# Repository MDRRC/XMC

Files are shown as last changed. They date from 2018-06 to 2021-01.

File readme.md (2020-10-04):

# Xpressnet Manual Control

The XpressNet Manual Control (Xmc) is manual control for the [XPressnet bus](www.lenzusa.com/1newsite1/Manuals/xpressnet.pdf) based on 

 * An [Maple Mini STM32 board](https://www.leaflabs.com/maple/) variant from China with **128K flash** memory and not the 64K variant!
 * RS485 driver IC
 * AT24C256 memory IC for storage of settings and locomotive data.
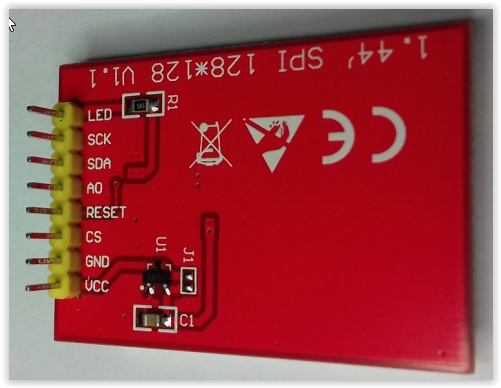
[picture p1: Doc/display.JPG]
 * 128*128 pixel ST7735 LCD. When ordering a display make sure the pinning is the same as shown in image below
 * Push buttons for controlling functions / accesory decoders / menu related actions. 
 * Pulse switch for setting speed / menu related actions.
 
The user interface is nearly the same as with the WMC application and it's tried to reuse / update library's created for WMC.

## Tested with
 * [MDRRC-II](http://members.home.nl/robert.evers/mdrrc2.htm) Response ok. 
 * [Roco MultiMaus as master](https://www.roco.cc/en/product/5215-multimaus-0-0-0-0-0-004001-0/products.html) OK for locs, turnouts not tested yet.

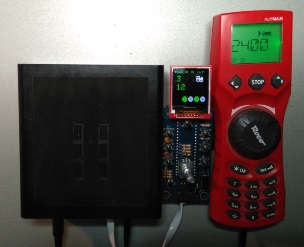
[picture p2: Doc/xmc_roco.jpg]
 
 
## Schematic
The [schematic](https://github.com/MDRRC/XMC/blob/master/Doc/xmc_schematic.pdf) of the XMC.

## PCB front and back side.
The PCB from the front and back. 
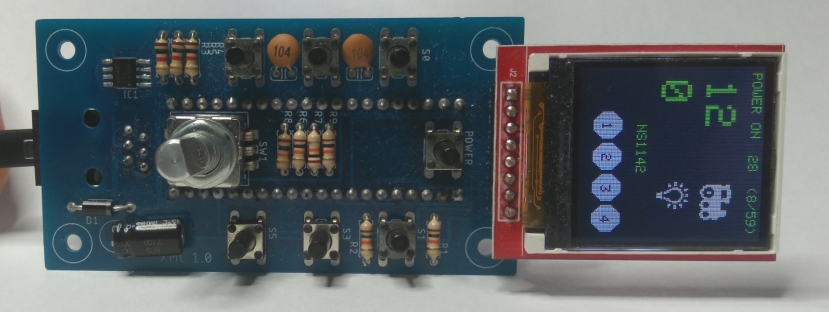
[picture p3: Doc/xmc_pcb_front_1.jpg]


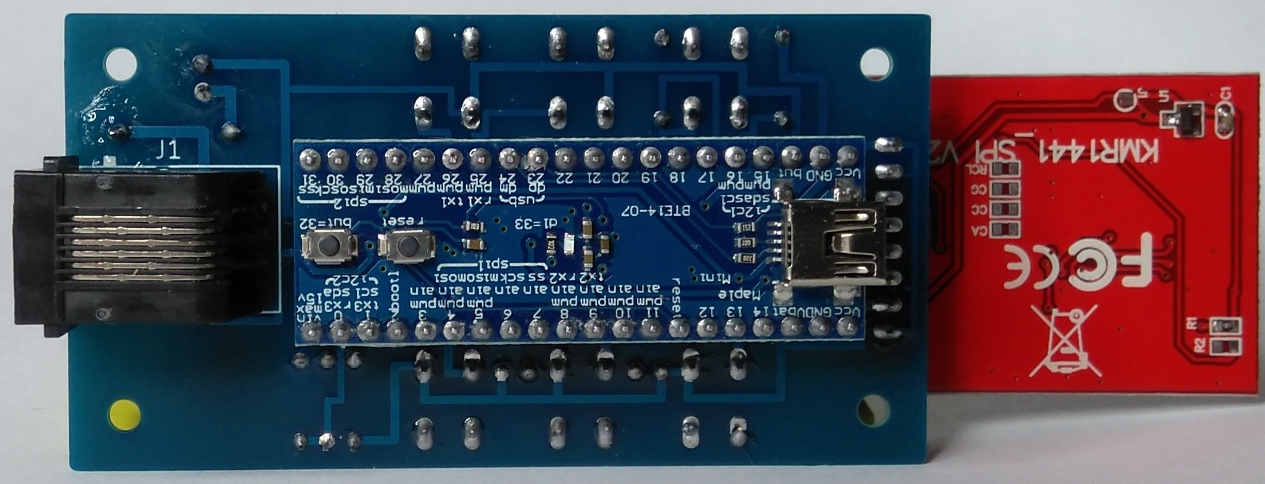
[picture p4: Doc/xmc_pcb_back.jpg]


## Programming the STM32 
The STM32 can be programmed without the need to build the software. By using a programming tool from the STM32 Arduino library the STM32 can be programmed with the buildin bootloader of the STM32 on the USB connection.
 * The [Stm32 Arduino library](https://github.com/rogerclarkmelbourne/Arduino_STM32) must be present on your PC.
 * Open the DOS box and enter command below (Location of files on your own PC might differ and the COM port will probably also be different, so change it accordingly!!)
 > C:/Arduino_STM32-master/tools/win/maple_upload.bat COM9 1 1EAF:0003 C:/LocationOfBinFileOnYourPc/Xmc.bin
 * The bin file is flashed into the STM32.
 * When ready, the screen stays gray for ~3 seconds and subsequent the start screen appears.
 
## Programming the STM32 with FLASHER-STM32
The STM32 can also be programmed with [Flasher-STM32](https://www.st.com/en/development-tools/flasher-stm32.html)
 * Connect an USB serial to TTL level (!) adapter to RX1 and TX1 (pin 25 and 26). The USB connector can NOT be used in this case for programmming!!! 
 * Connect the BOOT1 pin to ground when programming the STM32 out out the XMC PCB. 
 * Connect an USB cable to the USB connector of the STM32 module so it has supply voltage when programming the STM32 out out the XMC PCB. 
 * Follow instructions of chapter 5. Software update of [MDRRC-II Lite](https://github.com/MDRRC/Doc/blob/master/mdrrc_ii_lite.zip)
 * Select the XmcComplete.bin and flash the file. The bin file is WITH bootloader! 
 * When ready press RESet button, the screen stays gray for ~3 seconds and subsequent the start screen appears.   
 
## Used library's
If you want to build the code yourself or update / change the code following library's are required.
 * [XmcApp](https://github.com/MDRRC/XmcApp) the main state machine of the application.
 * [TinyFsm](https://github.com/digint/tinyfsm) for state machine framework.
 * [XpressNet](https://github.com/MDRRC/XpressNet) for XpressNet protocol.
 * [Bounce2](https://github.com/thomasfredericks/Bounce2) for debouncing switches.
Bounce requires an update for use in the XMC application, add the include and replace the attach function with code below
```c
#include "app_cfg.h"
 
void Bounce::attach(int pin, int mode)
{
  #ifdef MCU_STM32F103RB
  pinMode(pin, (WiringPinMode)(mode));
  #else
  pinMode(pin, mode);
  #endif
  this->attach(pin);
}
```
 * [Adafruit-ST7735-Library](https://github.com/adafruit/Adafruit-ST7735-Library) to control the display.
 * [WmcTft](https://github.com/MDRRC/WmcTft) for graphics within the XMC application.
 * [Adafruit-GFX-Library](https://github.com/adafruit/Adafruit-GFX-Library) for graphic control of the display.
 * [LocLib](https://github.com/MDRRC/LocLib) for handling locomotive data within the XMC application.
 * [WmcCv](https://github.com/MDRRC/WmcCv) for changing CV's.
 * [WmcCli](https://github.com/MDRRC/WmcCli) for the command line interface over the USB serial port.
 * [Stm32 Arduino library](https://github.com/rogerclarkmelbourne/Arduino_STM32), use the [1.0.0 release](https://github.com/rogerclarkmelbourne/Arduino_STM32/releases/tag/v1.0.0)! The most recent version at the master may give problems because of some changes.  
 
 In the Stm32 Arduino library
 * Remove or rename (.x for example) ..\Arduino_STM32-master\STM32F1\cores\maple\libmaple\usart.c so it's NOT build
 * Remove or rename (.x for example) ..\Arduino_STM32-master\STM32F1\cores\maple\libmaple\usart_f1.c so it's NOT build 
 * Remove or rename (.x for example) ..\Arduino_STM32-master\STM32F1\system\libmaple\usart_private.h so it's NOT build 
 
 The three files are in [XpressNet](https://github.com/MDRRC/XpressNet) and are required for correct handling of 9 bit communication handling.

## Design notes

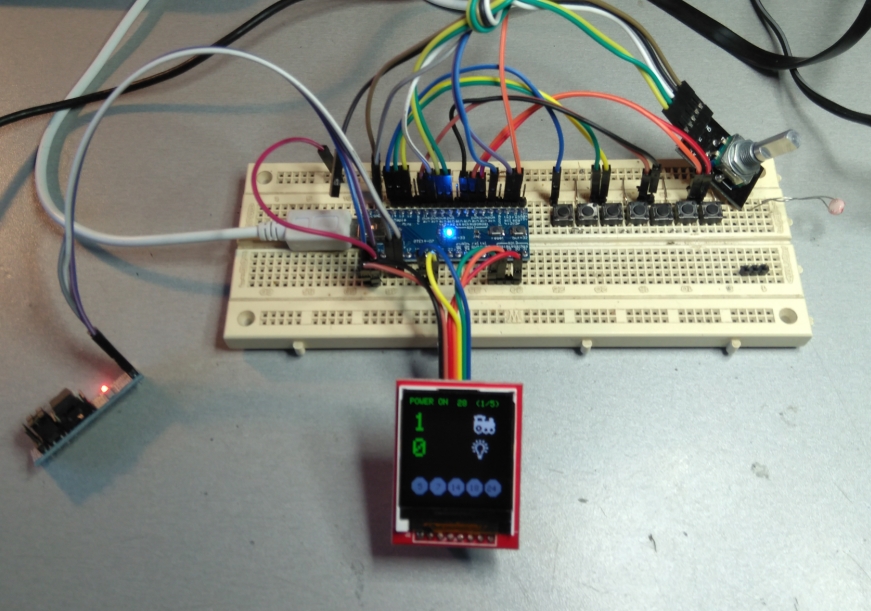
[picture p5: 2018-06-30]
Doc/xmc.jpg

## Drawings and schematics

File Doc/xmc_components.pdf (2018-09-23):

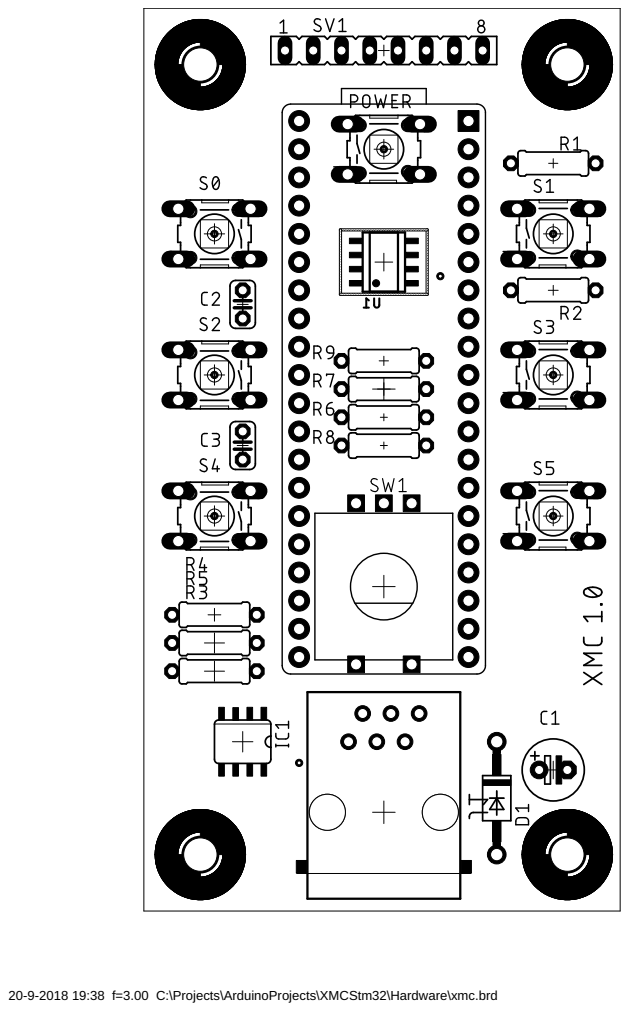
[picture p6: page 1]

20-9-2018 19:38 f=3.00 C:\Projects\ArduinoProjects\XMCStm32\Hardware\xmc.brd

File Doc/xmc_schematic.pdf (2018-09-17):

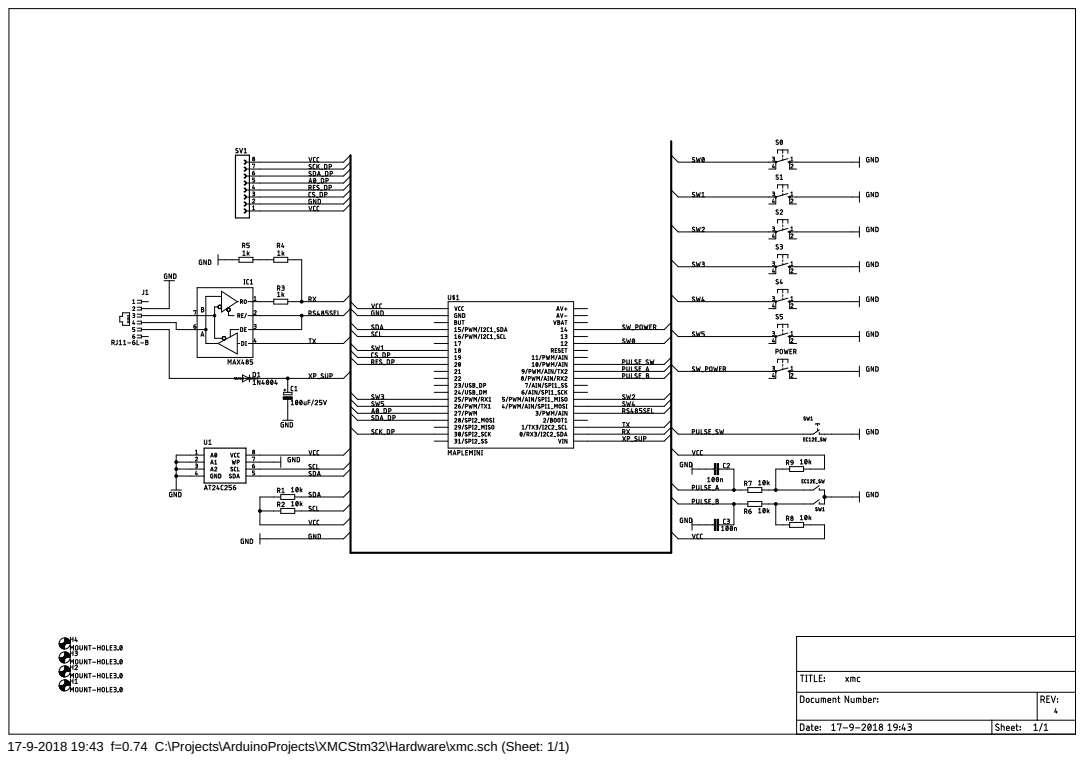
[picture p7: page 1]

17-9-2018 19:43 f=0.74 C:\Projects\ArduinoProjects\XMCStm32\Hardware\xmc.sch (Sheet: 1/1)

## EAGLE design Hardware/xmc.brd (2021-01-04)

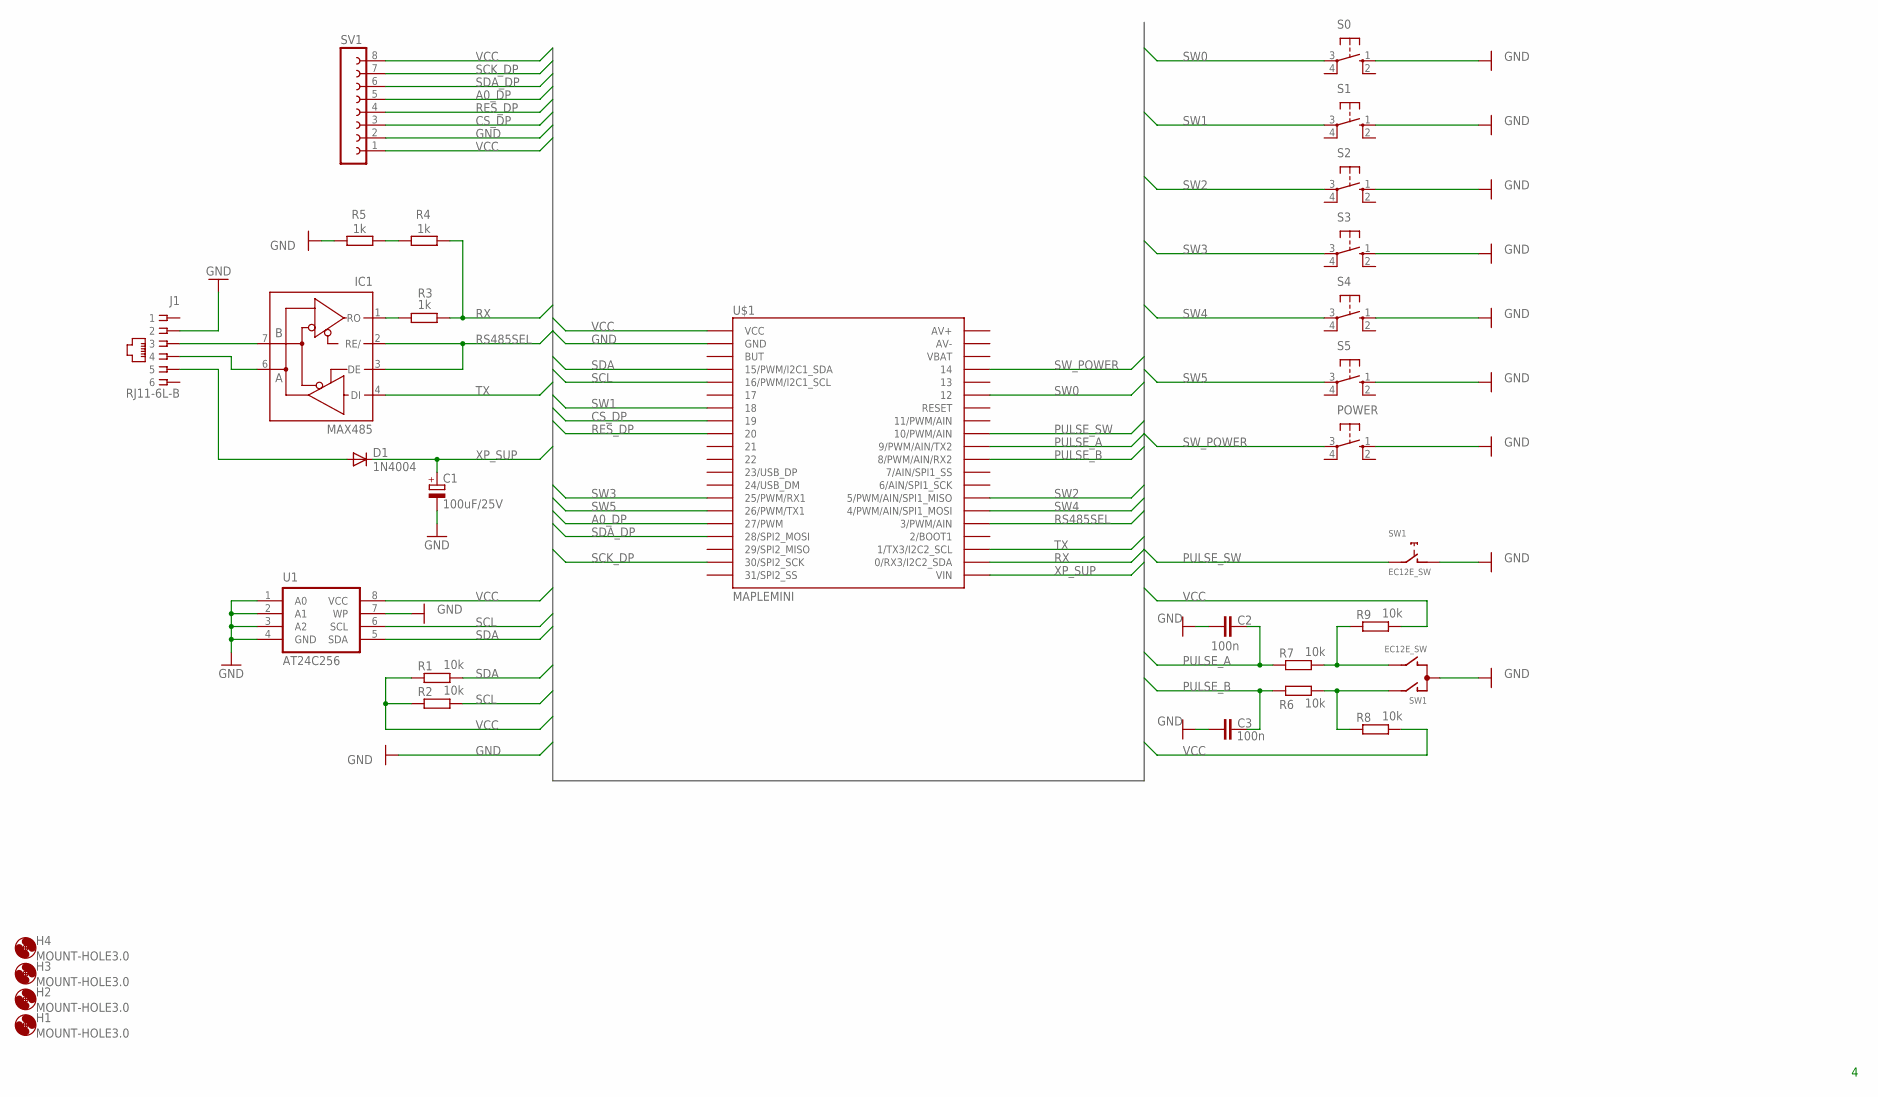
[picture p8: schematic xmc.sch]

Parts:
C1: 100uF/25V; E2,5-6
C2, C3: 100n; C025-024X044
D1: 1N4004; DO41-10
H1, H2, H3, H4: MOUNT-HOLE3.0; 3,0
IC1: MAX485; SO08
J1: RJ11-6L-B; RJ11-NO_SHIELD
POWER: 10-XX; B3F-10XX
R1, R2, R6, R7, R8, R9: 10k; 0207/7
R3, R4, R5: 1k; 0207/7
S0, S1, S2, S3, S4, S5: 10-XX; B3F-10XX
SV1: FE08-1; FE08
SW1: EC12E_SW; ALPS_EC12E_SW
U1: AT24C256; SO08-8S1
U$1: MAPLEMINI; 20-DIP

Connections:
A0_DP: SV1.5, U$1.16 (27/PWM)
CS_DP: SV1.3, U$1.8 (19)
GND: C1.-, C2.2, C3.2, IC1.5 (GND), J1.2, POWER.1 (S), R5.2, S0.1 (S), S1.1 (S), S2.1 (S), S3.1 (S), S4.1 (S), S5.1 (S), SV1.2, SW1.C, SW1.D (1), U1.1 (A0), U1.2 (A1), U1.3 (A2), U1.4 (GND), U1.7 (WP), U$1.2 (GND)
unnamed: R7.2, R9.1, SW1.B
unnamed: R6.2, R8.1, SW1.A
unnamed: D1.A, J1.5
unnamed: IC1.1 (RO), R3.1
unnamed: R4.2, R5.1
unnamed: IC1.7 (B), J1.3
unnamed: IC1.6 (A), J1.4
PULSE_A: C2.1, R7.1, U$1.31 (9/PWM/AIN/TX2)
PULSE_B: C3.1, R6.1, U$1.30 (8/PWM/AIN/RX2)
PULSE_SW: SW1.E (2), U$1.32 (10/PWM/AIN)
RES_DP: SV1.4, U$1.9 (20)
RS485SEL: IC1.2 (RE/), IC1.3 (DE), U$1.25 (3/PWM/AIN)
RX: R3.2, R4.1, U$1.22 (0/RX3/I2C2_SDA)
SCK_DP: SV1.7, U$1.19 (30/SPI2_SCK)
SCL: R2.2, U1.6 (SCL), U$1.5 (16/PWM/I2C1_SCL)
SDA: R1.2, U1.5 (SDA), U$1.4 (15/PWM/I2C1_SDA)
SDA_DP: SV1.6, U$1.17 (28/SPI2_MOSI)
SW0: S0.3, U$1.35 (12)
SW1: S1.3, U$1.7 (18)
SW2: S2.3, U$1.27 (5/PWM/AIN/SPI1_MISO)
SW3: S3.3, U$1.14 (25/PWM/RX1)
SW4: S4.3, U$1.26 (4/PWM/AIN/SPI1_MOSI)
SW5: S5.3, U$1.15 (26/PWM/TX1)
SW_POWER: POWER.3, U$1.37 (14)
TX: IC1.4 (DI), U$1.23 (1/TX3/I2C2_SCL)
VCC: IC1.8 (VCC), R1.1, R2.1, R8.2, R9.2, SV1.1, SV1.8, U1.8 (VCC), U$1.1 (VCC)
XP_SUP: C1.+, D1.C, U$1.21 (VIN)

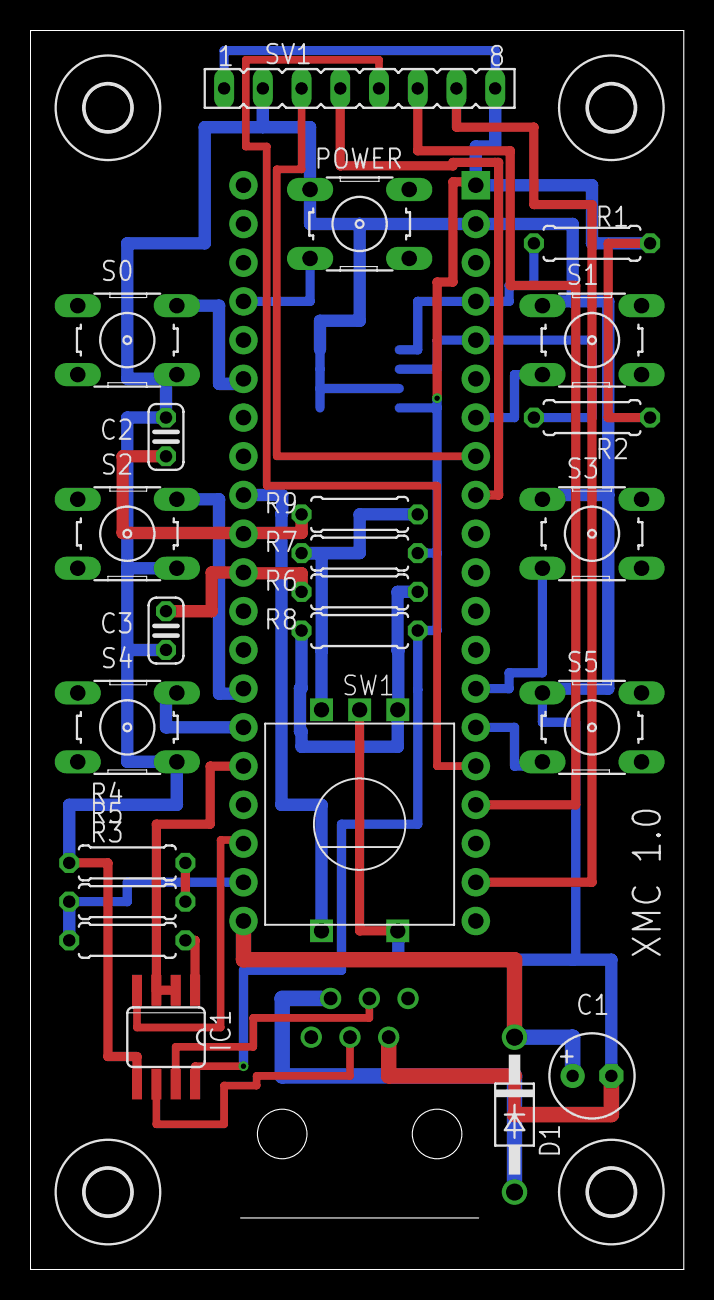
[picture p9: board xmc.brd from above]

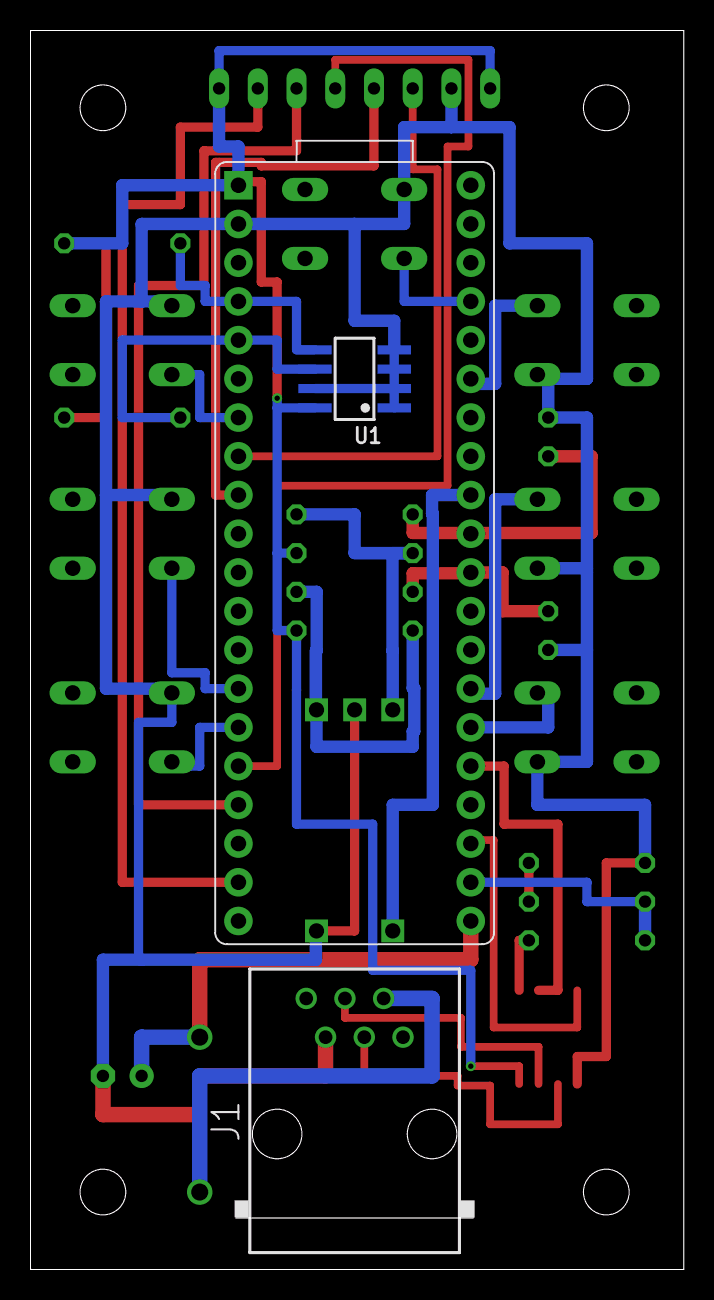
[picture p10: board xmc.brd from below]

Board: 2 copper layers, 42.8 x 81.3 mm, 30 parts (3 on the bottom side), 30 nets.

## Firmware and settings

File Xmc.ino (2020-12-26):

/***********************************************************************************************************************
   @file     Xmc.ino
   @ingroup  Application
   @brief    Main application of the XMC (XPressNet Manual Control)
 **********************************************************************************************************************/

/***********************************************************************************************************************
   I N C L U D E S
 **********************************************************************************************************************/
#include "Bounce2.h"
#include "fsmlist.hpp"
#include "xmc_app.h"
#include "xmc_event.h"
#include <Arduino.h>

/***********************************************************************************************************************
   E X P O R T E D   S Y M B O L   D E F I N I T I O N S (defines, typedefs)
 **********************************************************************************************************************/
#define XMC_TIMEOUT_100MS 100
#define XMC_TIMEOUT_500MS 500
#define XMC_TIMEOUT_3SEC 3000

#define XMC_PULSE_SWITCH_CHECK_TIMEOUT 100
#define XMC_ENCODER_PIN_A PA2
#define XMC_ENCODER_PIN_B PA3
#define XMC_ENCODER_PIN_PB PA1

#define XMC_SWITCH_POWER PC13
#define XMC_SWITCH_0 PC15
#define XMC_SWITCH_1 PB4
#define XMC_SWITCH_2 PA6
#define XMC_SWITCH_3 PA10
#define XMC_SWITCH_4 PA7
#define XMC_SWITCH_5 PA9

/***********************************************************************************************************************
   D A T A   D E C L A R A T I O N S (exported, local)
 **********************************************************************************************************************/

/**
 * Variables.
 */

Bounce xmcPulseSwitchPushButton = Bounce();
Bounce xmcPulseSwitchPower      = Bounce();
Bounce xmcPulseSwitch0          = Bounce();
Bounce xmcPulseSwitch1          = Bounce();
Bounce xmcPulseSwitch2          = Bounce();
Bounce xmcPulseSwitch3          = Bounce();
Bounce xmcPulseSwitch4          = Bounce();
Bounce xmcPulseSwitch5          = Bounce();

updateEvent3sec xmcUpdateEvent3Sec;
xpNetEventUpdate xmcXpNetUpdate;
pushButtonsEvent xmcPushButtonEvent;
pulseSwitchEvent wmcPulseSwitchEvent;
updateEvent100msec xmcUpdateEvent100msec;
updateEvent500msec xmcUpdateEvent500msec;

unsigned long xmcTimer100msec;
unsigned long xmcTimer500msec;
unsigned long xmcTimerMsec3Sec;
unsigned long xmcTimerPulseSwitch;
unsigned long xmcTimerPulseSwitchPushButton;

bool turnedWhilePressed           = false;
unsigned int encoder0PosActual    = 0;
volatile unsigned int encoder0Pos = 0;
uint8_t Runled                    = 0;

/***********************************************************************************************************************
   L O C A L   F U N C T I O N S
 **********************************************************************************************************************/

/***********************************************************************************************************************
 */
static void XmcUpdate3Sec(void)
{
    if (millis() - xmcTimerMsec3Sec > XMC_TIMEOUT_3SEC)
    {
        xmcTimerMsec3Sec = millis();
        send_event(xmcUpdateEvent3Sec);
    }
}

/***********************************************************************************************************************
 */
static void xmcUpdate100msec(void)
{
    if (millis() - xmcTimer100msec >= XMC_TIMEOUT_100MS)
    {
        xmcTimer100msec = millis();
        send_event(xmcUpdateEvent100msec);
    }
}

/***********************************************************************************************************************
 */
static void xmcUpdate500msec(void)
{
    if (millis() - xmcTimer500msec >= XMC_TIMEOUT_500MS)
    {
        xmcTimer500msec = millis();
        send_event(xmcUpdateEvent500msec);

        if (Runled != 0)
        {
            digitalWrite(PB1, LOW);
            Runled = 0;
        }
        else
        {
            digitalWrite(PB1, HIGH);
            Runled = 1;
        }
    }
}

/***********************************************************************************************************************
 */
void doEncoderA()
{
    // look for a low-to-high on channel A
    if (digitalRead(XMC_ENCODER_PIN_A) == HIGH)
    {
        // check channel B to see which way encoder is turning
        if (digitalRead(XMC_ENCODER_PIN_B) == LOW)
        {
            // CW
            encoder0Pos = encoder0Pos + 1;
        }
        else
        {
            // CCW
            encoder0Pos = encoder0Pos - 1;
        }
    }
    else // must be a high-to-low edge on channel A
    {
        // check channel B to see which way encoder is turning
        if (digitalRead(XMC_ENCODER_PIN_B) == HIGH)
        {
            // CW
            encoder0Pos = encoder0Pos + 1;
        }
        else
        {
            // CCW
            encoder0Pos = encoder0Pos - 1;
        }
    }
}

/***********************************************************************************************************************
 */
int8_t DecoderUpdate(void)
{
    int8_t Delta = 0;
    if (encoder0Pos != encoder0PosActual)
    {
        Delta             = encoder0Pos - encoder0PosActual;
        encoder0PosActual = encoder0Pos;
    }

    return (Delta);
}

/***********************************************************************************************************************
   E X P O R T E D   F U N C T I O N S
 **********************************************************************************************************************/

/***********************************************************************************************************************
 @brief
 @param
 @return     None
**********************************************************************************************************************/
void setup()
{
    Serial.begin(115200);

    /* Init the pulse / rotary encoder. */
    pinMode(XMC_ENCODER_PIN_A, INPUT_PULLUP);
    pinMode(XMC_ENCODER_PIN_B, INPUT_PULLUP);
    attachInterrupt(digitalPinToInterrupt(XMC_ENCODER_PIN_A), doEncoderA, FALLING);

    /* Init debounces for switches. */
    pinMode(XMC_ENCODER_PIN_PB, INPUT_PULLUP);
    xmcPulseSwitchPushButton.interval(100);
    xmcPulseSwitchPushButton.attach(XMC_ENCODER_PIN_PB);

    pinMode(XMC_SWITCH_POWER, INPUT_PULLUP);
    xmcPulseSwitchPower.interval(100);
    xmcPulseSwitchPower.attach(XMC_SWITCH_POWER);

    pinMode(XMC_SWITCH_0, INPUT_PULLUP);
    xmcPulseSwitch0.interval(100);
    xmcPulseSwitch0.attach(XMC_SWITCH_0);

    pinMode(XMC_SWITCH_1, INPUT_PULLUP);
    xmcPulseSwitch1.interval(100);
    xmcPulseSwitch1.attach(XMC_SWITCH_1);

    pinMode(XMC_SWITCH_2, INPUT_PULLUP);
    xmcPulseSwitch2.interval(100);
    xmcPulseSwitch2.attach(XMC_SWITCH_2);

    pinMode(XMC_SWITCH_3, INPUT_PULLUP);
    xmcPulseSwitch3.interval(100);
    xmcPulseSwitch3.attach(XMC_SWITCH_3);

    pinMode(XMC_SWITCH_4, INPUT_PULLUP);
    xmcPulseSwitch4.interval(100);
    xmcPulseSwitch4.attach(XMC_SWITCH_4);

    pinMode(XMC_SWITCH_5, INPUT_PULLUP);
    xmcPulseSwitch5.interval(100);
    xmcPulseSwitch5.attach(XMC_SWITCH_5);

    /* Run led. */
    pinMode(PB1, OUTPUT);

    /* Init timers. */
    xmcTimer500msec               = millis();
    xmcTimerMsec3Sec              = millis();
    xmcTimerPulseSwitch           = millis();
    xmcTimerPulseSwitchPushButton = millis();

    /* Kick the state machine. */
    fsm_list::start();
}

/***********************************************************************************************************************
 @brief
 @param
 @return     None
**********************************************************************************************************************/
void loop()
{
    int8_t Delta = 0;

    /* Update bounce for switches. */
    xmcPulseSwitchPushButton.update();
    xmcPulseSwitchPower.update();
    xmcPulseSwitch0.update();
    xmcPulseSwitch1.update();
    xmcPulseSwitch2.update();
    xmcPulseSwitch3.update();
    xmcPulseSwitch4.update();
    xmcPulseSwitch5.update();

    /* Check for status change of switches and generate event is required. */
    if (xmcPulseSwitchPower.rose() == true)
    {
        xmcPushButtonEvent.Button = button_power;
        send_event(xmcPushButtonEvent);
    }

    if (xmcPulseSwitch0.rose() == true)
    {
        xmcPushButtonEvent.Button = button_0;
        send_event(xmcPushButtonEvent);
    }

    if (xmcPulseSwitch1.rose() == true)
    {
        xmcPushButtonEvent.Button = button_1;
        send_event(xmcPushButtonEvent);
    }

    if (xmcPulseSwitch2.rose() == true)
    {
        xmcPushButtonEvent.Button = button_2;
        send_event(xmcPushButtonEvent);
    }

    if (xmcPulseSwitch3.rose() == true)
    {
        xmcPushButtonEvent.Button = button_3;
        send_event(xmcPushButtonEvent);
    }

    if (xmcPulseSwitch4.rose() == true)
    {
        xmcPushButtonEvent.Button = button_4;
        send_event(xmcPushButtonEvent);
    }

    if (xmcPulseSwitch5.rose() == true)
    {
        xmcPushButtonEvent.Button = button_5;
        send_event(xmcPushButtonEvent);
    }

    /* Timer update events. */
    XmcUpdate3Sec();
    xmcUpdate100msec();
    xmcUpdate500msec();

    /* Pulse switch handling. */
    if (xmcPulseSwitchPushButton.fell() == true)
    {
        xmcTimerPulseSwitchPushButton = millis();
    }
    else if (xmcPulseSwitchPushButton.rose() == true)
    {
        if (turnedWhilePressed == false)
        {
            if (millis() - xmcTimerPulseSwitchPushButton > 3000)
            {
                wmcPulseSwitchEvent.Status = pushedlong;
                send_event(wmcPulseSwitchEvent);
            }
            else if (millis() - xmcTimerPulseSwitchPushButton < 300)
            {
                wmcPulseSwitchEvent.Status = pushedShort;
                send_event(wmcPulseSwitchEvent);
            }
            else if (millis() - xmcTimerPulseSwitchPushButton < 1100)
            {
                wmcPulseSwitchEvent.Status = pushedNormal;
                send_event(wmcPulseSwitchEvent);
            }
        }
        else
        {
            turnedWhilePressed         = false;
            wmcPulseSwitchEvent.Status = released;
            send_event(wmcPulseSwitchEvent);
        }
    }
    else if ((millis() - xmcTimerPulseSwitch) > XMC_PULSE_SWITCH_CHECK_TIMEOUT)
    {
        /* Update pulse switch turn events if turned.*/
        xmcTimerPulseSwitch = millis();
        Delta               = DecoderUpdate();
        if (Delta != 0)
        {
            if (xmcPulseSwitchPushButton.read() == LOW)
            {
                turnedWhilePressed         = true;
                wmcPulseSwitchEvent.Status = pushturn;
            }
            else
            {
                wmcPulseSwitchEvent.Status = turn;
            }

            wmcPulseSwitchEvent.Delta = Delta;

            send_event(wmcPulseSwitchEvent);
        }
    }

    /* Kick XpNet module. */
    send_event(xmcXpNetUpdate);
}

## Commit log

2018-07-02 Initial schematic.
2018-07-09 Hard coded timer values replaced with defines.
    [Xmc.ino]
2018-07-11 Button names updated, a button can have a user defined function, so F removed of name. F0 would indicate Function 0, but button 0 can have other assigned functions.
2018-07-11 Schematic updated.
2018-07-12 Button assignment to MapleMini pins changed for easier PCB design, the Maple Mini is located on the backside of the PCB.
2018-07-14 Updated button inputs to schematic version 3.
2018-08-04 Added PCB examples.
2018-08-06 Programming of STM32 added.
2018-09-17 Schematic C1 added value and IC1 type corrected.
2020-03-16 RX and TX pin for STM Flasher added.
2020-06-03 Added handling of two serial (uart) related files.
2020-06-11 Flashing added text when STM module is programmed out the XMC PCB and rename example added.
2020-06-14 Added complete image of XMC (including maple_nini_boot20.bin) from https://github.com/rogerclarkmelbourne/STM32duino-bootloader
2020-12-26 Same as WMC adding faster loc selection. After push button is released while selecting locs send an release event so actual selected loc data can be retrieved.
2021-01-04 Added Eagle files.
    [xmc.brd, xmc.sch]
2021-01-04 Version 2.2.0. * "faster" selection of locomotives, when selecting the loc address is set to white color. * When a selected loc is controlled by another (XPressNet) device the loc symbol is turned ye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
    Tested with MDRRC-II (lite) and Roco LocMaus and in both situations the yellow symbol is not shown when expected.. On the Roco setup only when the set speed of the other device was zero, on MDRRC-II 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
    Be aware, settings will be lost!

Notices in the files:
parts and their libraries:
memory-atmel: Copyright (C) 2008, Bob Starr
